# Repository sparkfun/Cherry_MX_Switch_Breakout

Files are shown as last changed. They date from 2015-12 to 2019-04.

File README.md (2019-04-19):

SparkFun Cherry MX Switch Breakout
====================

<table class="table table-hover table-striped table-bordered">
  <tr align="center">
   <td><a href="https://www.sparkfun.com/products/13773">SparkFun Cherry MX Switch Breakout</a></td>
   <td><a href="https://www.sparkfun.com/products/13773">Cherry MX Switch Soldered on Breakout</a></td>
  </tr>
  <tr align="center">
    <td><i>SparkFun Cherry MX Switch Breakout </i></td>
    <td><i>Cherry MX Switch Soldered on Breakout</i></td>
  </tr>
</table>

[*SparkFun Cherry MX Switch Breakout (BOB-13773)*](https://www.sparkfun.com/products/13773)

Cherry MX Keyswitches are top-of-the-line mechanical keyboard switches. They’re satisfyingly “clicky”, reliable up to tens-of-millions of key presses, and a standard in gaming and programming keyboards across the globe. With the SparkFun Cherry MX Switch Breakout we have made the switches more easily adaptable to breadboard or perfboard-based projects. The Cherry MX Switch Breakout is a perfect prototyping tool for projects ranging from a single-key user-input to fully-custom 101-key keyboards.

Repository Contents
-------------------

* **/Hardware** - All Eagle design files (.brd, .sch)
* **/Production** - Production panel files (.brd)

Documentation
--------------
* **[Hookup Guide](https://learn.sparkfun.com/tutorials/cherry-mx-switch-breakout-hookup-guide)** - Basic hookup guide for the SparkFun Cherry MX Switch Breakout.

Product Versions
----------------
* [BOB-13773](https://www.sparkfun.com/products/13773)- Initial release of the Cherry MX Switch Breakout

Version History
---------------
* [V_1.0](https://github.com/sparkfun/Cherry_MX_Switch-Breakout/releases/tag/V_1.0) - Initial release of Cherry MX Switch Breakout.

License Information
-------------------

This product is _**open source**_! 

Please review the LICENSE.md file for license information. 

If you have any questions or concerns on licensing, please contact techsupport@sparkfun.com.

Distributed as-is; no warranty is given.

- Your friends at SparkFun.

_<COLLABORATION CREDIT>_

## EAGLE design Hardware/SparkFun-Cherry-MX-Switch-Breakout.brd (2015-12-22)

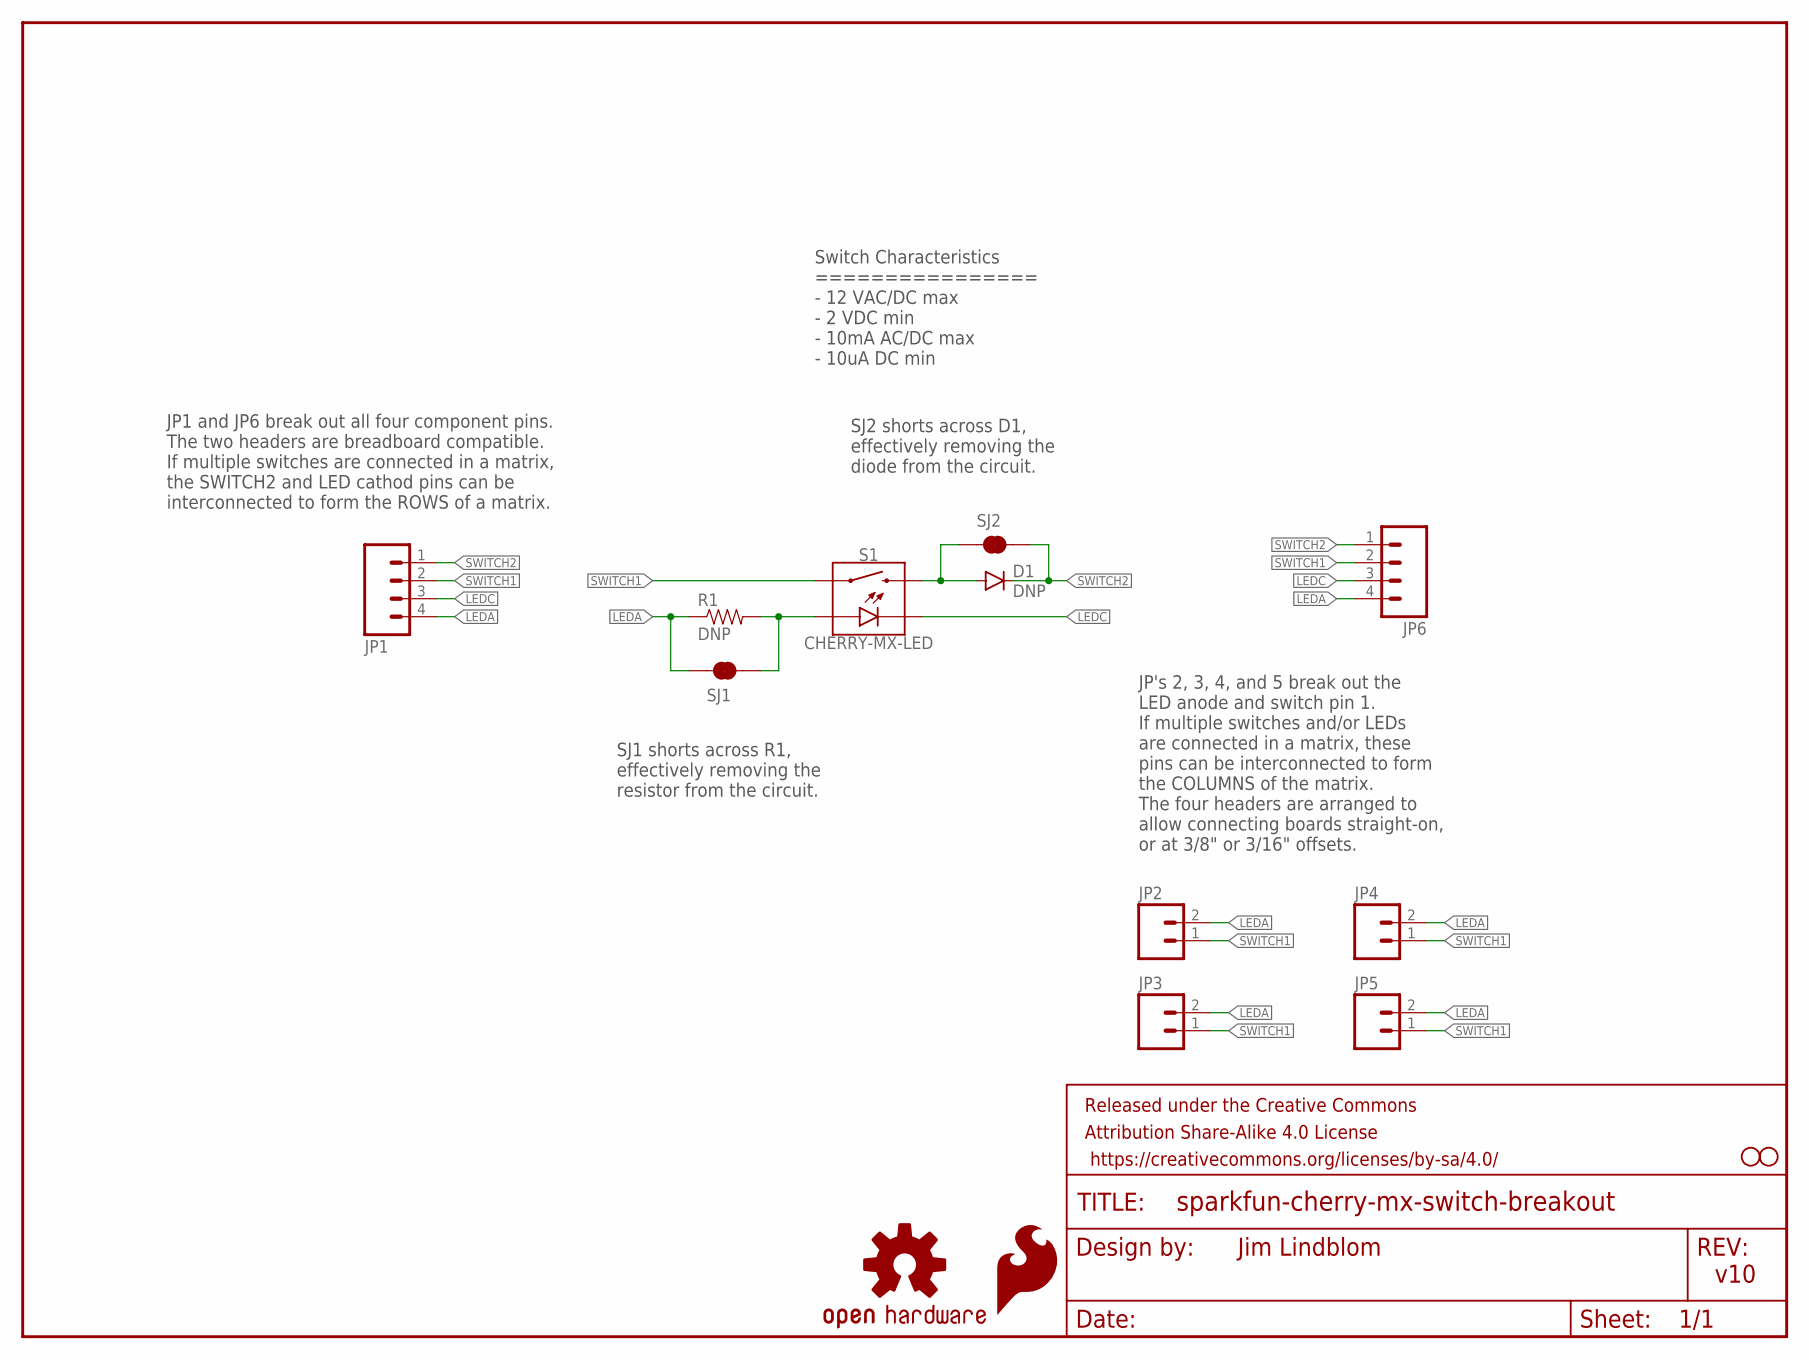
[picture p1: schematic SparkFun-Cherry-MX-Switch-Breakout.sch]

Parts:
D1: DNP; DIODE-PTH-0.1
FRAME1: FRAME-LETTER; CREATIVE_COMMONS
JP1, JP6: M04NO_SILK_ALL_ROUND; 1X04_NO_SILK_ALL_ROUND
JP2, JP3, JP4, JP5: M021X02_NO_SILK; 1X02_NO_SILK
LOGO1: OSHW-LOGOS; OSHW-LOGO-S
LOGO2: SFE_LOGO_FLAME.1_INCH; SFE_LOGO_FLAME_.1
R1: DNP; AXIAL-0.1
S1: CHERRY-MX-LED
SJ1, SJ2: JUMPER-PAD-2-NC_BY_TRACENO_SILK; PAD-JUMPER-2-NC_BY_TRACE_NO_SILK
STANDOFF1, STANDOFF2: STAND-OFF2-56; STAND-OFF-2-56

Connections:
LEDA: JP1.4, JP2.2, JP3.2, JP4.2, JP5.2, JP6.4, R1.P$1 (1), SJ1.1
LEDC: JP1.3, JP6.3, S1.K (C)
unnamed: R1.P$2 (2), S1.A, SJ1.2
unnamed: D1.A, S1.S2, SJ2.1
SWITCH1: JP1.2, JP2.1, JP3.1, JP4.1, JP5.1, JP6.2, S1.S1
SWITCH2: D1.C, JP1.1, JP6.1, SJ2.2

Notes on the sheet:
v10
Jim Lindblom
SJ1 shorts across R1, effectively removing the resistor from the circuit.
SJ2 shorts across D1, effectively removing the diode from the circuit.
JP's 2, 3, 4, and 5 break out the LED anode and switch pin 1. If multiple switches and/or LEDs are connected in a matrix, these pins can be interconnected to form the COLUMNS of the matrix. The four headers are arranged to allow connecting boards straight-on, or at 3/8" or 3/16" offsets.
JP1 and JP6 break out all four component pins. The two headers are breadboard compatible. If multiple switches are connected in a matrix, the SWITCH2 and LED cathod pins can be interconnected to form the ROWS of a matrix.
Switch Characteristics ================ - 12 VAC/DC max - 2 VDC min - 10mA AC/DC max - 10uA DC min

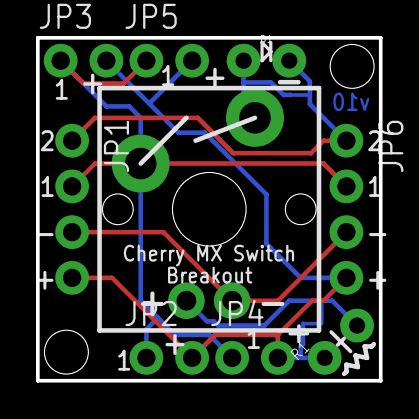
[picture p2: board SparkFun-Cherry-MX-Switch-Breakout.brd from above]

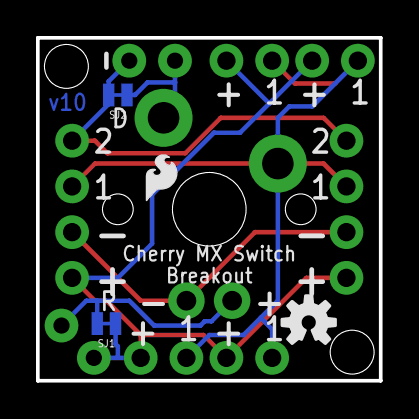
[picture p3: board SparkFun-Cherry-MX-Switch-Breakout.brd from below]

Board: 2 copper layers, 19.1 x 19.1 mm, 16 parts (4 on the bottom side), 6 nets.

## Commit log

2015-11-23 Initial commit of board design
    [SparkFun-Cherry-MX-Switch-Breakout.brd, SparkFun-Cherry-MX-Switch-Breakout.sch]
2015-11-23 Rearranging resistor and diode packages and standoffs.
    [SparkFun-Cherry-MX-Switch-Breakout.brd, SparkFun-Cherry-MX-Switch-Breakout.sch]
2015-11-23 Polishing resistor and diode silk.
    [SparkFun-Cherry-MX-Switch-Breakout.brd, SparkFun-Cherry-MX-Switch-Breakout.sch]
2015-11-23 Removing extra 2-pin connector.
    [SparkFun-Cherry-MX-Switch-Breakout.brd, SparkFun-Cherry-MX-Switch-Breakout.sch]
2015-12-22 Adjsting some silk, setting version to v10.
    [SparkFun-Cherry-MX-Switch-Breakout.brd, SparkFun-Cherry-MX-Switch-Breakout.sch]

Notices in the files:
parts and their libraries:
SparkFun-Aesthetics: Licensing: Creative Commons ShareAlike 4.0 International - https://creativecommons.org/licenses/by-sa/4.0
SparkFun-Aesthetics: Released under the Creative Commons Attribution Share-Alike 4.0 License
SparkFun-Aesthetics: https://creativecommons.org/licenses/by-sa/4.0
